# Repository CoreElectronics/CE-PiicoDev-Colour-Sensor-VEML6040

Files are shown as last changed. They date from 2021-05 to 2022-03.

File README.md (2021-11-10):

# PiicoDev® Colour Sensor VEML6040



This is the repo for the Core Electronics [PiicoDev Colour Sensor VEML6040](https://core-electronics.com.au/catalog/product/view/sku/CE07823).

Use the PiicoDev® Colour Sensor to measure the RGBW components of light, or even extract the colour of an object so you can compare apples with oranges. Onboard is a high accuracy colour sensor - the VEML6040 boasts 16-bit precision for each channel (R, G, B, W). By using PiicoDev adapters and cables, you can connect to this sensor without soldering - or use the standard breakout header if you prefer breadboard prototyping. Whichever you prefer, the PiicoDev guides will get you measuring colour in no time!

### Features

Small size, high accuracy
Onboard High-CRI LED for measuring reflected light
Great guides to get you started
PiicoDev connector, compatible with Qwiic and STEMMA QT (3.3V only)
2.54mm breakout for breadboarding/prototyping
Manufactured and supported in Australia by Core Electronics

### Getting Started Guides

- For [Micro:bit](https://core-electronics.com.au/tutorials/micro-bit/piicodev-colour-sensor-veml6040-micro-bit-guide.html)
- For [Raspberry Pi Pico](https://core-electronics.com.au/tutorials/raspberry-pi-pico/piicodev-colour-sensor-veml6040-raspberry-pi-pico-guide.html)
- For [Raspberry Pi](https://core-electronics.com.au/tutorials/raspberry-pi/piicodev-colour-sensor-veml6040-raspberry-pi-guide.html)

### Technical Specifications

- Address: 0x10,
- 16-bit precision per channel
- Dimensions: 25.4x25.4mm
- Mounting Holes: 2x M2.5
- Disable LED by pulling LED Pin to Ground.

# License
This project is open source - please review the LICENSE.md file for further licensing information.

If you have any technical questions, or concerns about licensing, please contact technical support on the [Core Electronics forums](https://forum.core-electronics.com.au/).

*\"PiicoDev\" and the PiicoDev logo are trademarks of Core Electronics Pty Ltd.*

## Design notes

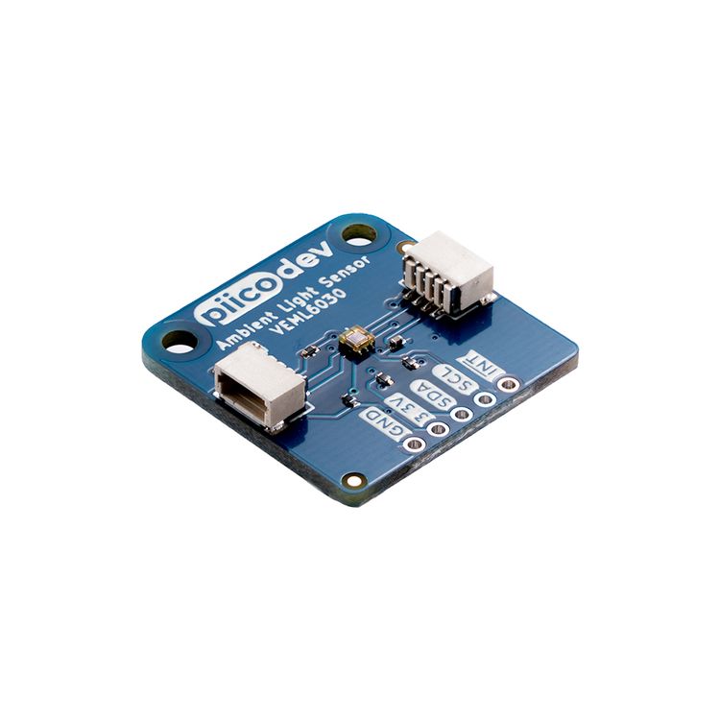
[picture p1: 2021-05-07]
Documents/piicodev-ambient-light-sensor.jpg

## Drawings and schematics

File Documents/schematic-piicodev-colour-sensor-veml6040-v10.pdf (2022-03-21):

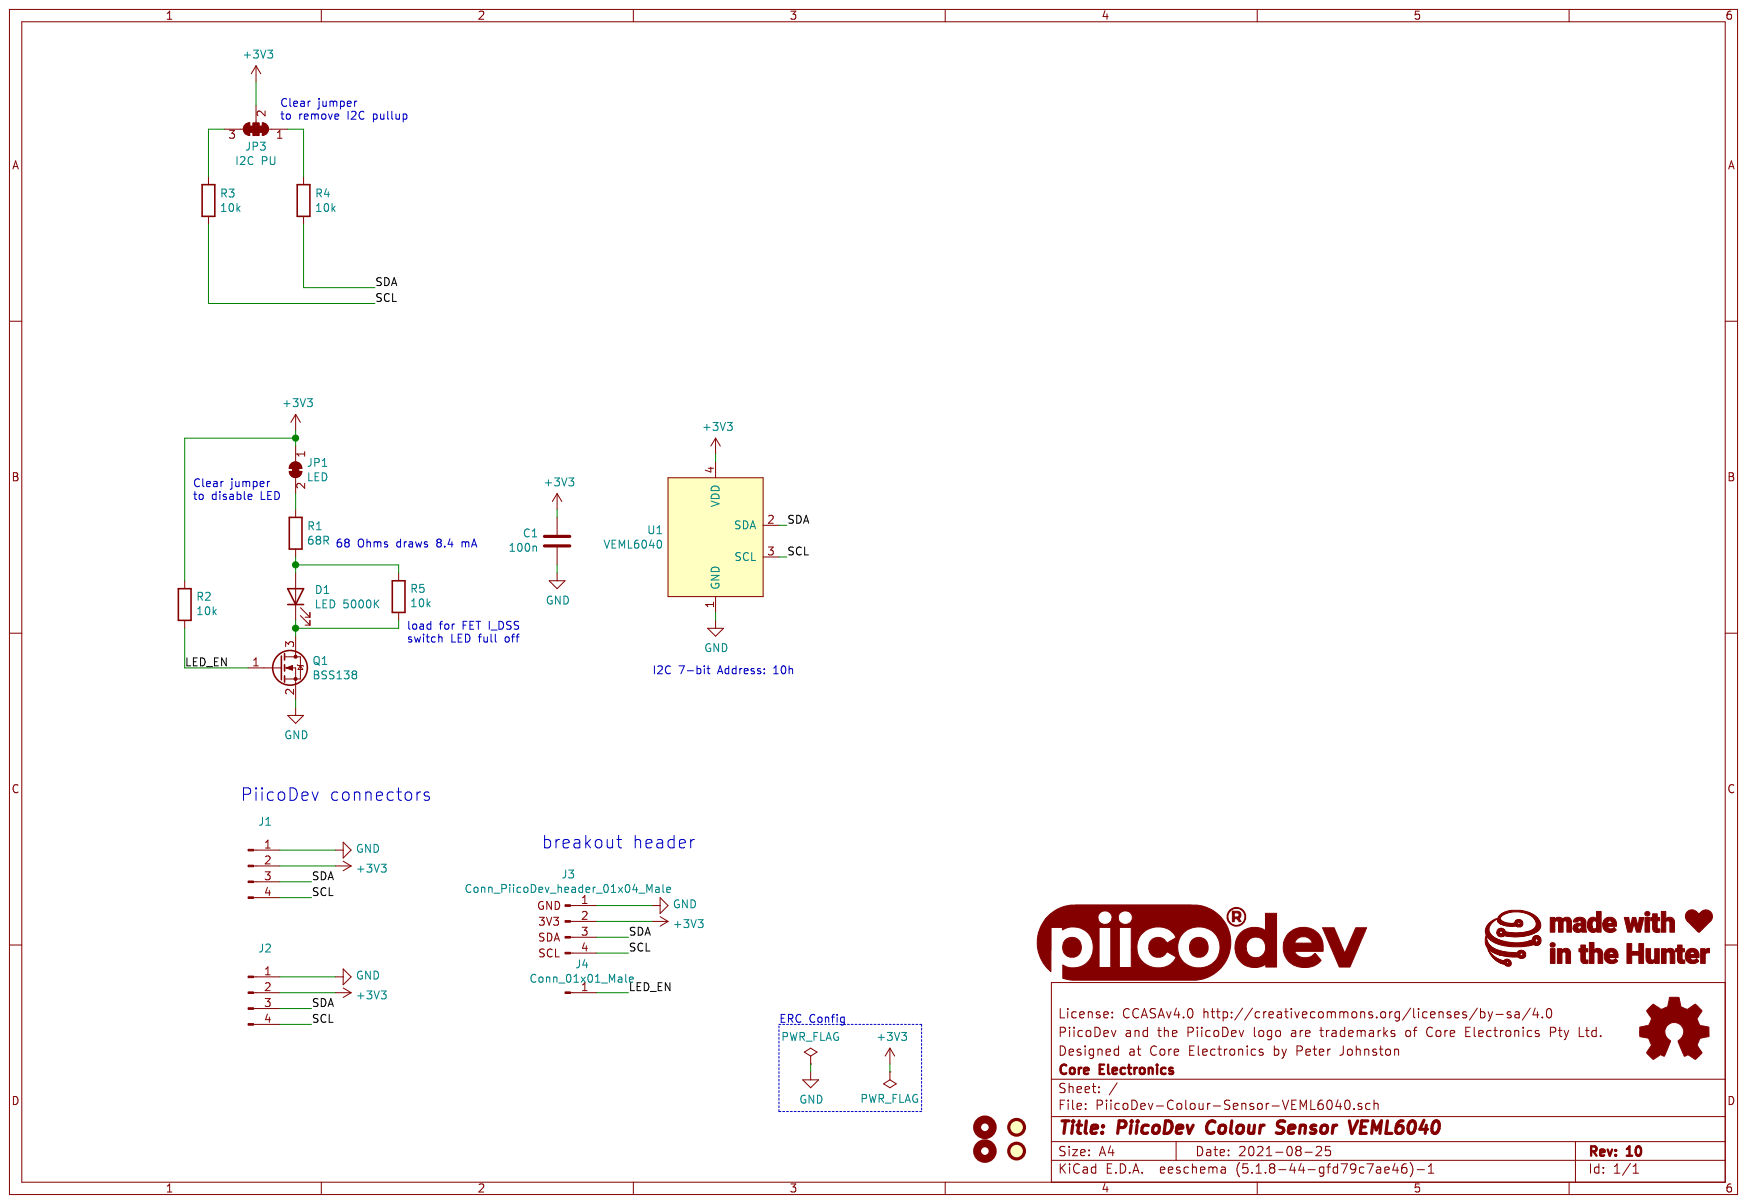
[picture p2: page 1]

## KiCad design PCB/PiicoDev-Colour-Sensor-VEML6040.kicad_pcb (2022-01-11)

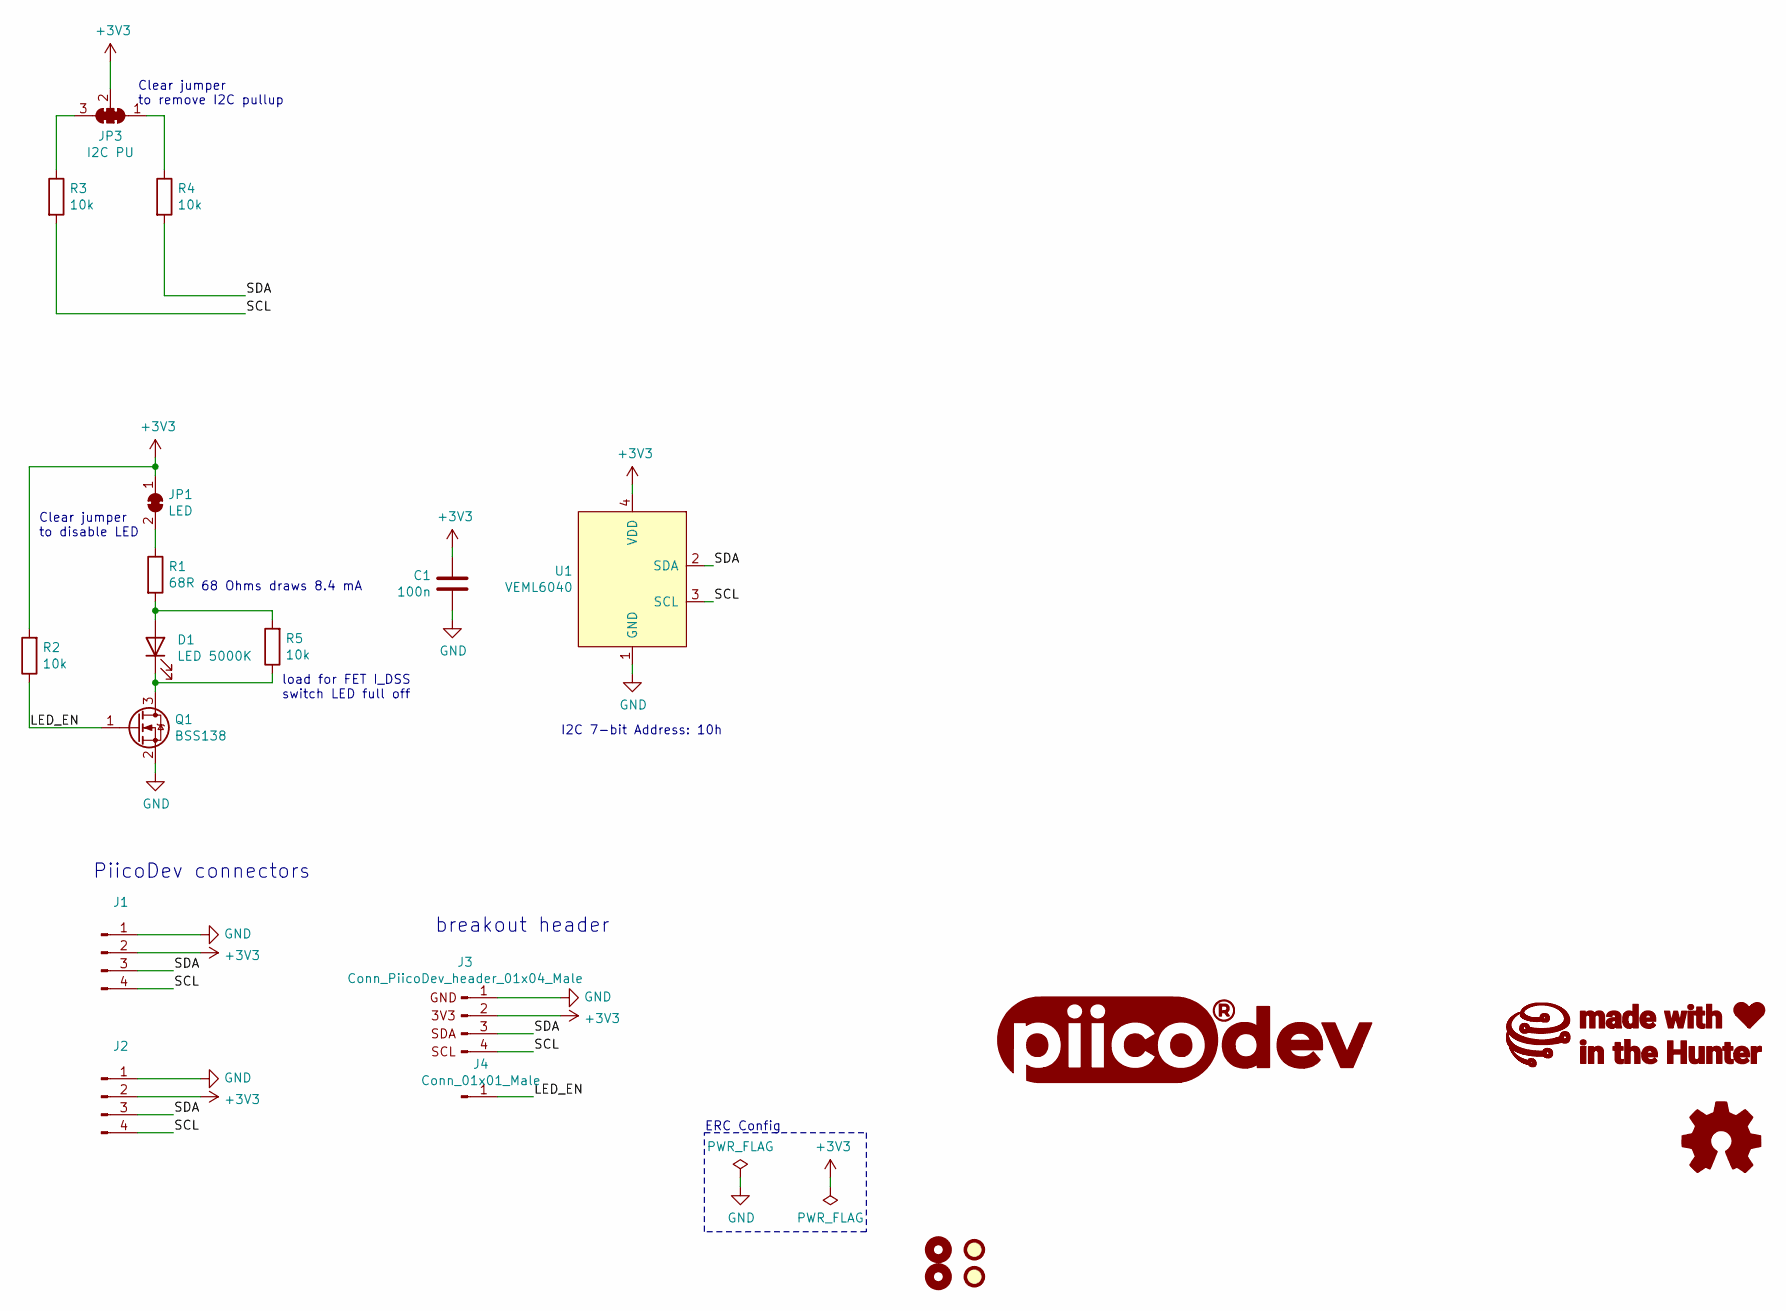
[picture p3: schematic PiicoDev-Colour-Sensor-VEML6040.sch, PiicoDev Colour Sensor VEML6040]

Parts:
C1: 100n; C_0402_1005Metric
D1: LED 5000K; LED_1208_3020Metric_Heatsink
FID1, FID2: Fiducial; Fiducial_1mm_Mask2mm
G1: LOGO_CoreElectronics_no-text; CoreElectronics_logo_5mm
G2: LOGO_piico; piicodev_logo_14.2x3.4mm
G3: LOGO_made-with-love; piicodev_logo_14.2x3.4mm
H1, H4: MountingHole; MountingHole_2.7mm_M2.5_PadClearance_1.2
J1, J2: JST_SH_SM04B-SRSS-TB_1x04-1MP_P1.00mm_Horizontal
J3: Conn_PiicoDev_header_01x04_Male; PiicoDev_header_4pin
J4: Conn_01x01_Male; PiicoDev_header_1pin_LED
JP1: LED; SolderJumper-2_P1.3mm_Bridged_RoundedPad1.0x1.5mm
JP3: I2C PU; SolderJumper-3_P1.3mm_Closed_RoundedPad1.0x1.5mm_NumberLabe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
LOGO1: Logo_Open_Hardware_Small; oshw
Q1: BSS138; SOT-23
R1: 68R; R_0402_1005Metric
R2, R3, R4, R5: 10k; R_0402_1005Metric
U1: VEML6040; VISHAY_VEML6040_2X1.25X1

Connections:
+3V3: C1.2, J1.2, J2.2, J3.2, JP1.1 (A), JP3.2 (C), R2.2, U1.4 (VDD)
/LED_EN: J4.1, Q1.1 (G), R2.1
/SCL: J1.4, J2.4, J3.4, R3.2, U1.3 (SCL)
/SDA: J1.3, J2.3, J3.3, R4.2, U1.2 (SDA)
GND: C1.1, J1.1, J2.1, J3.1, Q1.2 (S), U1.1 (GND)
unnamed: D1.1 (K), Q1.3 (D), R5.1
unnamed: D1.2 (A), R1.2, R5.2
unnamed: JP1.2 (B), R1.1
unnamed: JP3.1 (A), R4.1
unnamed: JP3.3 (B), R3.1

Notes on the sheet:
Clear jumper to remove I2C pullup
PiicoDev connectors
breakout header
I2C 7-bit Address: 10h
ERC Config
Clear jumper to disable LED
68 Ohms draws 8.4 mA
load for FET I_DSS switch LED full off

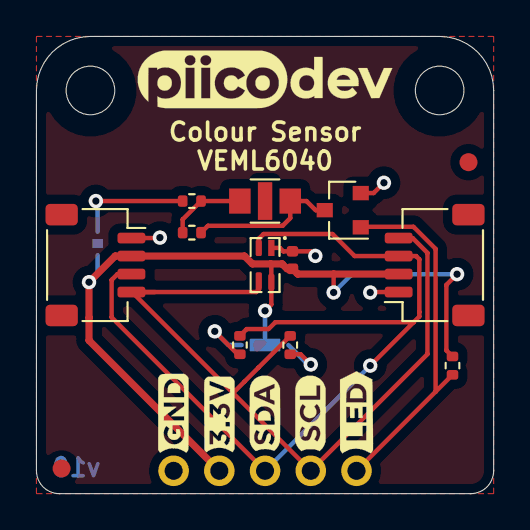
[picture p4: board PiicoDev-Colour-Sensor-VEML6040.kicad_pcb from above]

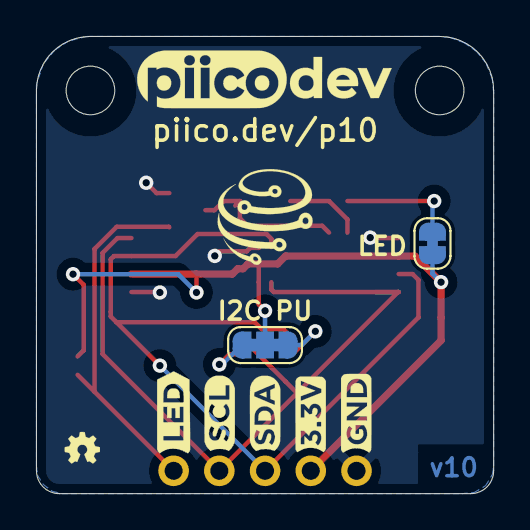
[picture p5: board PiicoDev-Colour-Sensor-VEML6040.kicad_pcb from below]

Board: 2 copper layers, 25.4 x 25.4 mm, 23 parts (7 on the bottom side), 10 nets.

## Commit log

2021-05-10 Replace power LED with illumination LED
    [PiicoDev-Colour-Sensor-VEML6040.kicad_pcb, PiicoDev-Colour-Sensor-VEML6040.sch]
2021-05-11 Update version number
    [PiicoDev-Colour-Sensor-VEML6040.sch]
2021-05-11 Tweak layout
    [PiicoDev-Colour-Sensor-VEML6040.kicad_pcb]
2021-06-15 Add LED current note
    [PiicoDev-Colour-Sensor-VEML6040.sch]
2021-08-24 Add LED bypass resistor
    [PiicoDev-Colour-Sensor-VEML6040.kicad_pcb, PiicoDev-Colour-Sensor-VEML6040.sch]
2021-08-24 Change date
    [PiicoDev-Colour-Sensor-VEML6040.sch]
2021-11-04 Make LED_1208_3020 SMT instead of through-hole
    [PiicoDev-Colour-Sensor-VEML6040.kicad_pcb]
2021-12-05 correct schematic pdf
2022-01-11 Change 4k7 resistors to 10k
    [PiicoDev-Colour-Sensor-VEML6040.kicad_pcb, PiicoDev-Colour-Sensor-VEML6040.sch]
2022-03-21 Update schematic-piicodev-colour-sensor-veml6040-v10.pdf
    update resistor values 4k7 to 10k

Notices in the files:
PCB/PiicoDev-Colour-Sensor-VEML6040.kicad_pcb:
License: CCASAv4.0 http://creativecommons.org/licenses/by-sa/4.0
